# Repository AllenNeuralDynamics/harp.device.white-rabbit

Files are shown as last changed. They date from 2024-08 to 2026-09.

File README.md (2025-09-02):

An RP2040-based 16-output [Harp](https://github.com/harp-tech/protocol)-compliant Clock Synchronizer. 

This device can serve as a drop-in replacement for the [Harp-Tech Clock Synchronizer](https://github.com/harp-tech/device.clocksynchronizer) with added capabilities.

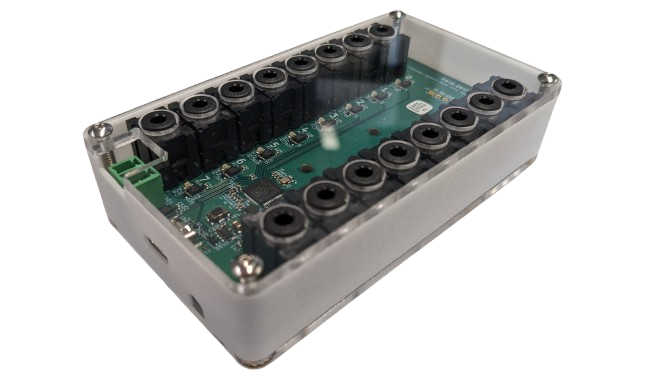
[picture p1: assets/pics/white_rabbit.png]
PCB


## Features
* 16 output channels for distributing clocks to other devices
* 1 input channel for receiving and synchronizing to another clock source
* 1 Additional Auxiliary Output, providing one of the following at a time:
  * PPS output
  * serial output of the time at user-specifiable baud-rate
* "Used channel detection." Device can identify which channels are in use.

## Ordering ➡ 💸
You can now order V1.0.0 from PCBWay:
* [white-rabbit board](https://www.pcbway.com/project/shareproject/W777629ASS64_W777629ASS46_white_rabbit_v1_0_0_gerbers_1c23dd35.html). Select **PCB + Assembly**

These printed circuit boards are made on-demand.

You will also need:
* [3D Printed Enclosure Walls and Laser Cut Lids](https://cad.onshape.com/documents/e58143a7c9dd2652647e9623/w/90e72faf89a0a2a445ca0911/e/b03806c0bc46a31dc8d5c2c5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)
  * right click the component to export each part.

## Auxiliary Output
This device features an auxiliary output that can either produce a *pulse-per-second* (PPS) or UART message at the start of the whole second.
This external signa enables Harp devices to additionally further synchronize with *non*-Harp devices.

### PPS Output
This device optionally outputs a 1[Hz] signal with a 50% duty cycle on the whole second.
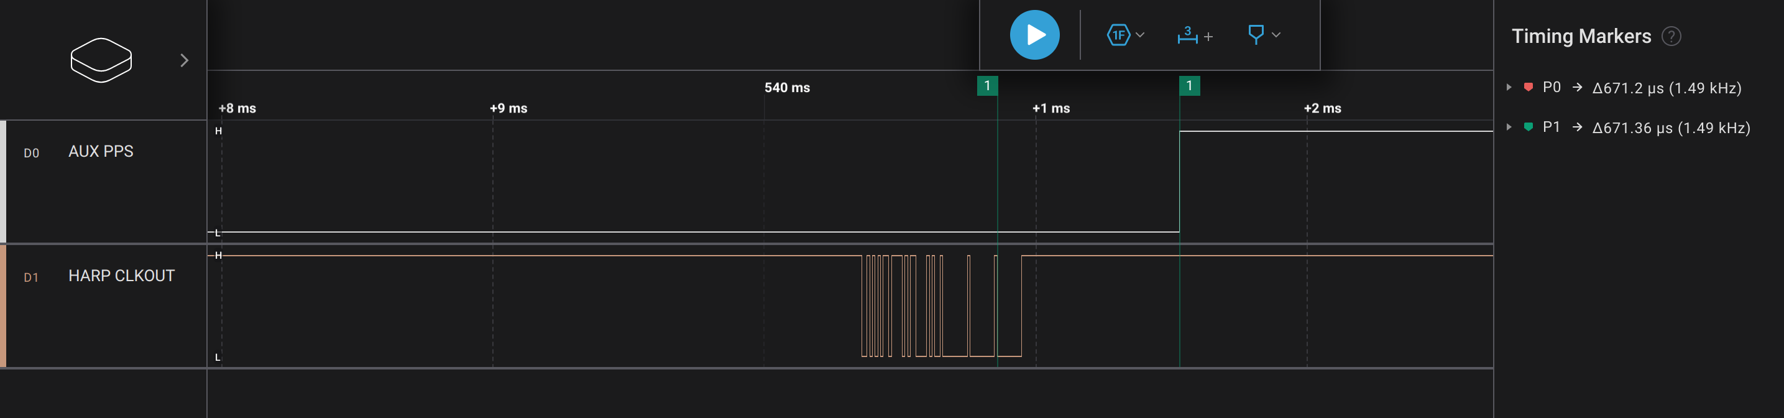
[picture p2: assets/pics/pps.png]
PPS

Error from the nominal Harp time is < 1[us].

This feature is available on the AUX Port (3-pin terminal block).

### AUX UART Output
This device optionally outputs a the current time in seconds at the start of the whole second.
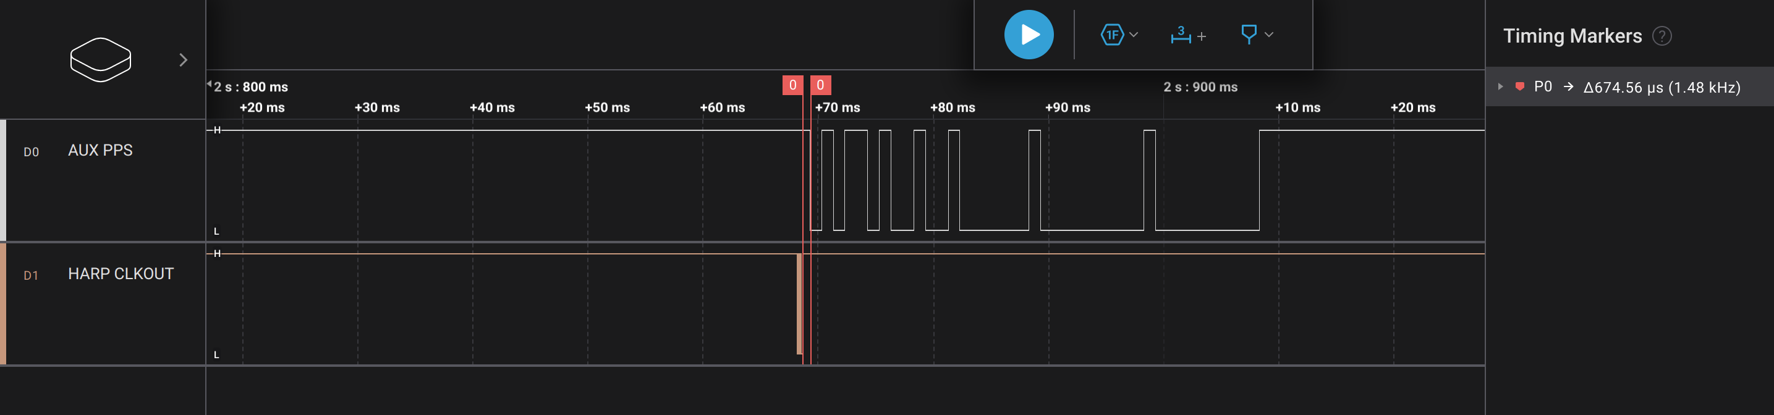
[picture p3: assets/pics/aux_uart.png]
AUX_UART

Error from the nominal Harp time is < 3[us].

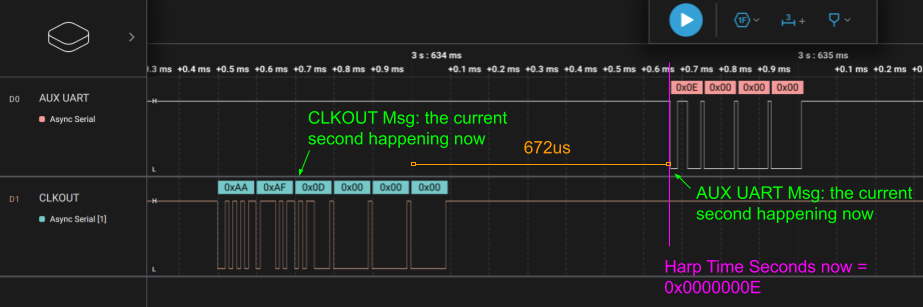
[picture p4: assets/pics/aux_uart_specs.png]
AUX_UART_ERROR


This feature is available on the AUX Port (3-pin terminal block), and the baud rate is configurable via Harp Protocol (U32 in Register 36).

## PCBA Enclosure
For the enclosure design, see the companion [OnShape project](https://cad.onshape.com/documents/e58143a7c9dd2652647e9623/w/90e72faf89a0a2a445ca0911/e/b03806c0bc46a31dc8d5c2c5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).

## Developer Notes
In the firmware's **CMakeLists.txt**, adding (or uncommenting) the debug message below:
````cmake
add_definitions(-DDEBUG)
````
will *override* the Auxiliary port behavior to use the auxiliary uart for `printf`-style debug messages.
`PPS` and `AUX UART` features will not be available in debug mode.

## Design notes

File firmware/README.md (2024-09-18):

## Setting up the Build Environment

### Install Submodules
This project uses the [Harp Core RP2040](https://github.com/AllenNeuralDynamics/harp.core.rp2040) library as a submodule.
Install it with:
````
git submodule update --init
````

### Install Pico SDK
This project uses the [Pico SDK](https://github.com/raspberrypi/pico-sdk/tree/master).
The SDK needs to be downloaded and installed to a known folder on your PC.
Note that the PICO SDK also contains submodules (including TinyUSB), so you must ensure that they are also fetched with:
````
git clone git@github.com:raspberrypi/pico-sdk.git
git submodule update --init --recursive
````

### Point to Pico SDK
Recommended, but optional: define the `PICO_SDK_PATH` environment variable to point to the location where the pico-sdk was downloaded. i.e:
````
PICO_SDK_PATH=/home/username/projects/pico-sdk
````
On Linux, it may be preferrable to put this in your `.bashrc` file.

## Compiling the Firmware

### Without an IDE
From this directory, create a directory called build, enter it, and invoke cmake with:
````
mkdir build
cd build
cmake ..
````
If you did not define the `PICO_SDK_PATH` as an environment variable, you must pass it in here like so:
````
mkdir build
cd build
cmake -DPICO_SDK_PATH=/path/to/pico-sdk ..
````
After this point, you can invoke the auto-generated Makefile with `make`

## Flashing the Firmware
Press-and-hold the Pico's BOOTSEL button and power it up (i.e: plug it into usb).
At this point you do one of the following:
* drag-and-drop the created **\*.uf2** file into the mass storage device that appears on your pc.
* flash with [picotool](https://github.com/raspberrypi/picotool)

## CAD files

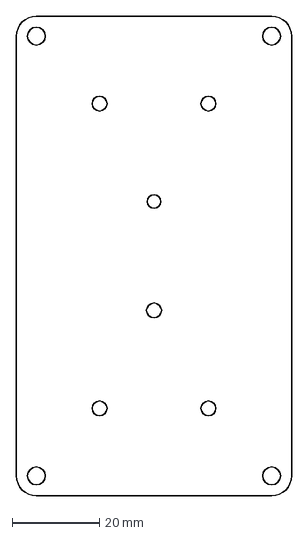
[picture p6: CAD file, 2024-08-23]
hardware/enclosure/exports/dxfs/offset/bottom_lid_offset.DXF
63.2 x 110.2 mm

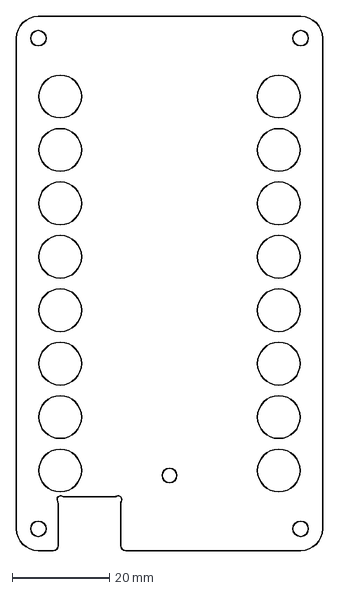
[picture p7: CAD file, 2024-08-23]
hardware/enclosure/exports/dxfs/original/top_lid.DXF
63.0 x 110.0 mm

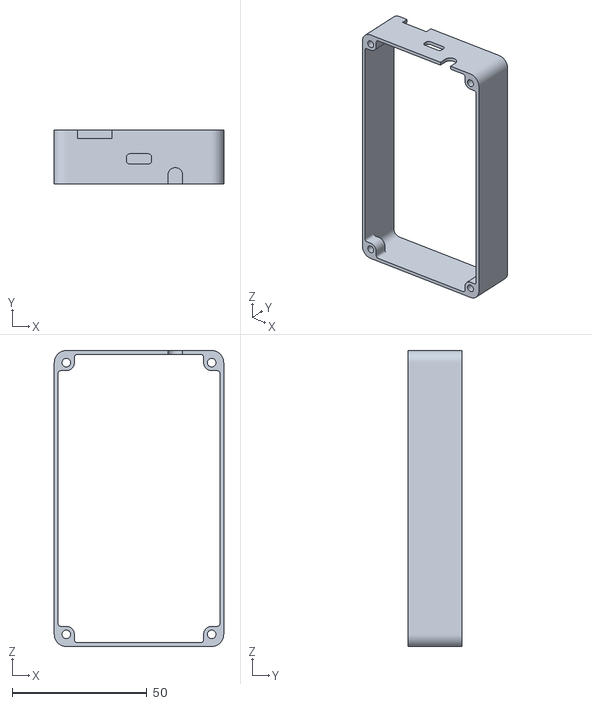
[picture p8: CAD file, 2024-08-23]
hardware/enclosure/exports/stls/case_walls.STL
63.0 x 19.9 x 110.0

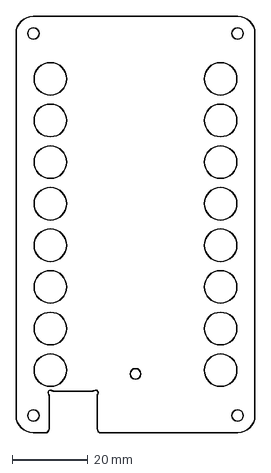
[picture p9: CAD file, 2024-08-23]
hardware/enclosure/exports/dxfs/offset/top_lid_offset.DXF
63.2 x 110.2 mm

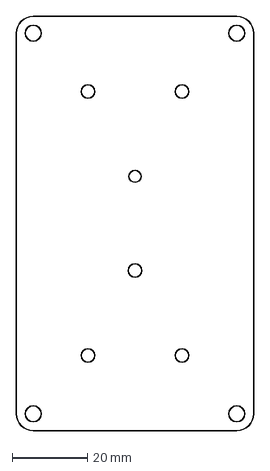
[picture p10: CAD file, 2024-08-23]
hardware/enclosure/exports/dxfs/original/bottom_lid.DXF
63.0 x 110.0 mm

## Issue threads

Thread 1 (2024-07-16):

Draft of register specification

bruno-f-cruz, 2024-07-16:
## Period generation of messages (Timer)
### Sends out periodic messages eg. 250hz (1 register for Event U32 counter, 1 Register for writing period/frequency)

e.g.:
```
 Timer:
    address: 33
    type: U32
    access: [Write, Event]
    description: Unitary counter that periodically produces a value at the frequency defined by register TimerFrequency.
  TimerFrequency:
    address: 34
    type: U8
    access: Write
    maskType: TimerRate
    description: Frequency at which the Timer will generate new values.
```

## IsConnected.
 U16 > each bit is a device/port connected(1) or not (0). Emit a message each time it changes.
eg.:
```
 DevicesConnected:
    address: 32
    type: U8
    access: Read
    maskType: ConnectedDevices
    description: Specifies which CLK_OUT ports have devices connected.
```

## Writable Seconds register
## Low 1kpbs / PPS

Poofjunior, 2024-07-17:
Ok, can I propose a few changes?

* 32: `connected_devices` instead of `DevicesConnected`
* 33: `heartbeat` instead of `Timer` (_[Heartbeat](https://en.wikipedia.org/wiki/Heartbeat_(computing)) has a standard meaning.)
* 34: `heartbeat_frequency_hz` instead of `TimerFrequency`
* 34: U16 instead of U8 and the value 0 - 1000 represents the actual publish rate instead of an enum of predefined values.

bruno-f-cruz, 2024-07-17:
I am fine with connected_devices as long as it is pascal casing :P

33 and 34 i really don't think we should call it heartbeat. For two reasons. 1) this register is not reporting the state of the device it is really just a "dumb" periodic event. 2) I think heartbeat is already co-opted by a recent proposal: https://github.com/harp-tech/protocol/pull/45

Poofjunior, 2024-07-17:
If not `heartbeat`, how about `counter` then?

Since these are scoped to Core and App registers, I'm totally ok with having overlapping names--especially since all core registers are [prefixed](https://harp-tech.org/protocol/Device.html#table---list-of-available-common-registers) with `R_`.

bruno-f-cruz, 2024-07-17:
Sure, the counter is ok. My only contention is whether to try to align interfaces across different devices if possible, as to only ask users to learn a single name, but if we want to go with something different i don't have a strong opinion. `Counter` sounds good.

Regarding the names, the decision is a bit more complicated. Since the bonsai/python interfaces are generated from the yml file, it is critical to have different names (otherwise users will have a really hard time knowing which one is which).

Poofjunior, 2024-07-17:
Ok, sounds good. `Counter` it is.

For the time when the message emits, is it critical that it falls on or near a particular whole number or multiple of a whole number?

bruno-f-cruz, 2024-07-17:
Nah do it whenever it crosses the expected time and the board is "available" to work. I would say that some deviation from the requested frequency is expected. At 250hz, 5% would be a good target?

Poofjunior, 2024-07-17:
Ok, coolies. Honestly, I expect it to be <1% deviation. Sending a USB transaction is the only "time-consuming" function device needs to execute. Nothing else blocks.

Poofjunior, 2024-07-18:
All right; here's what I've got so far:
````cpp
struct app_regs_t
{
    volatile uint16_t ConnectedDevices; // bitmask where each bit represents
                                         // whether a device is
                                         // connected (1) or disconnected (0)
                                         // to the corresponding clock output
                                         // channel.
    volatile uint32_t Counter;
    volatile uint16_t CounterFrequencyHz;
    volatile uint8_t AuxPortFn; // bit[0] = 1 --> slow uart
                                // bit[1] = 1 --> PPS
    // More app "registers" here.
};
````

We'll need to test these with Bonsai.

bruno-f-cruz, 2024-09-12:
I am closing this issue as we already have the spec

Closed 2024-09-12.

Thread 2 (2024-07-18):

Add Bonsai interface

bruno-f-cruz, 2024-07-18:
Follow the current spec:

https://github.com/AllenNeuralDynamics/harp.device.white-rabbit/blob/708e135fb53b5afd40ac85ea6d7713f9611dc87d/firmware/inc/white_rabbit_app.h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

bruno-f-cruz, 2024-08-01:
Closed by #3

Closed 2024-08-01.

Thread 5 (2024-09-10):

V1.0 TODOs

Poofjunior, 2024-09-10:
- [x] Check that heartbeat timestamps agree on a White Rabbit and a device synchronized to it.
- [x] Check that AUX PPS signal rising edge emits 672 microseconds after the start of the last byte of the last emitted CKLOUT message.
- [x] Check that AUX UART message first falling edge emits 672 microseconds after the start of the last byte of the last emitted CLKOUT message.
- [x] Check that time encoded by UART is the second that just elapsed.
- [x] Hardware/FW Versions available in Harp Protocol

Poofjunior, 2024-09-11:
For the last point:
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

Closed 2024-09-12.

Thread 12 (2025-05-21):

`ClockConfiguration` register is not set correctly

bruno-f-cruz, 2025-05-21:
Querying the register returns:

```
               None  ClockRepeater  ClockGenerator  RepeaterCapability  GeneratorCapability  ClockUnlock  ClockLock MessageType
Time                                                                                                                  
3.601605e+06  False          False           False               False                False        False      False        READ
```

Some of these are expected to be high for a clock generator:
https://harp-tech.org/protocol/Device.html#r_clock_config-u8--synchronization-clock-configuration

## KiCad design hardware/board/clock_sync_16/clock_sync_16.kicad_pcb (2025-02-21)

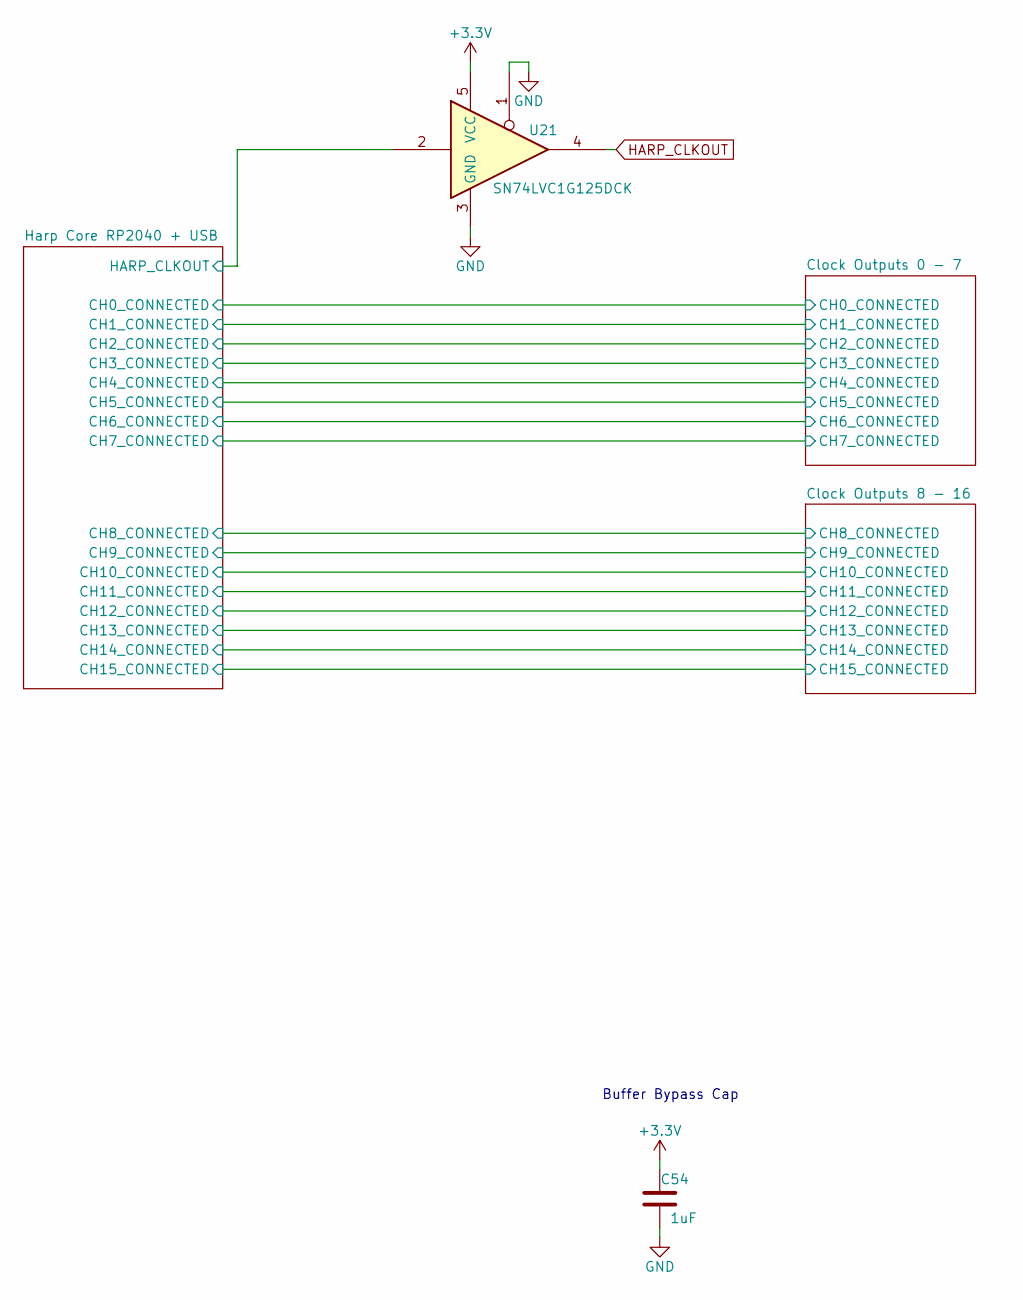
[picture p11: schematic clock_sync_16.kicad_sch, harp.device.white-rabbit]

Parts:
C54: 1uF; C_0402_1005Metric; Rated Voltage 35V
U21: SN74LVC1G125DCK; Texas_R-PDSO-G5_DCK-5

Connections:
+3.3V: C54.1, U21.5 (VCC); also elsewhere on the board
/Harp Core RP2040 + USB/HARP_CLKOUT: U21.2; also elsewhere on the board
GND: C54.2, U21.1, U21.3 (GND); also elsewhere on the board
HARP_CLKOUT: U21.4; also elsewhere on the board

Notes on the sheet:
Buffer Bypass Cap

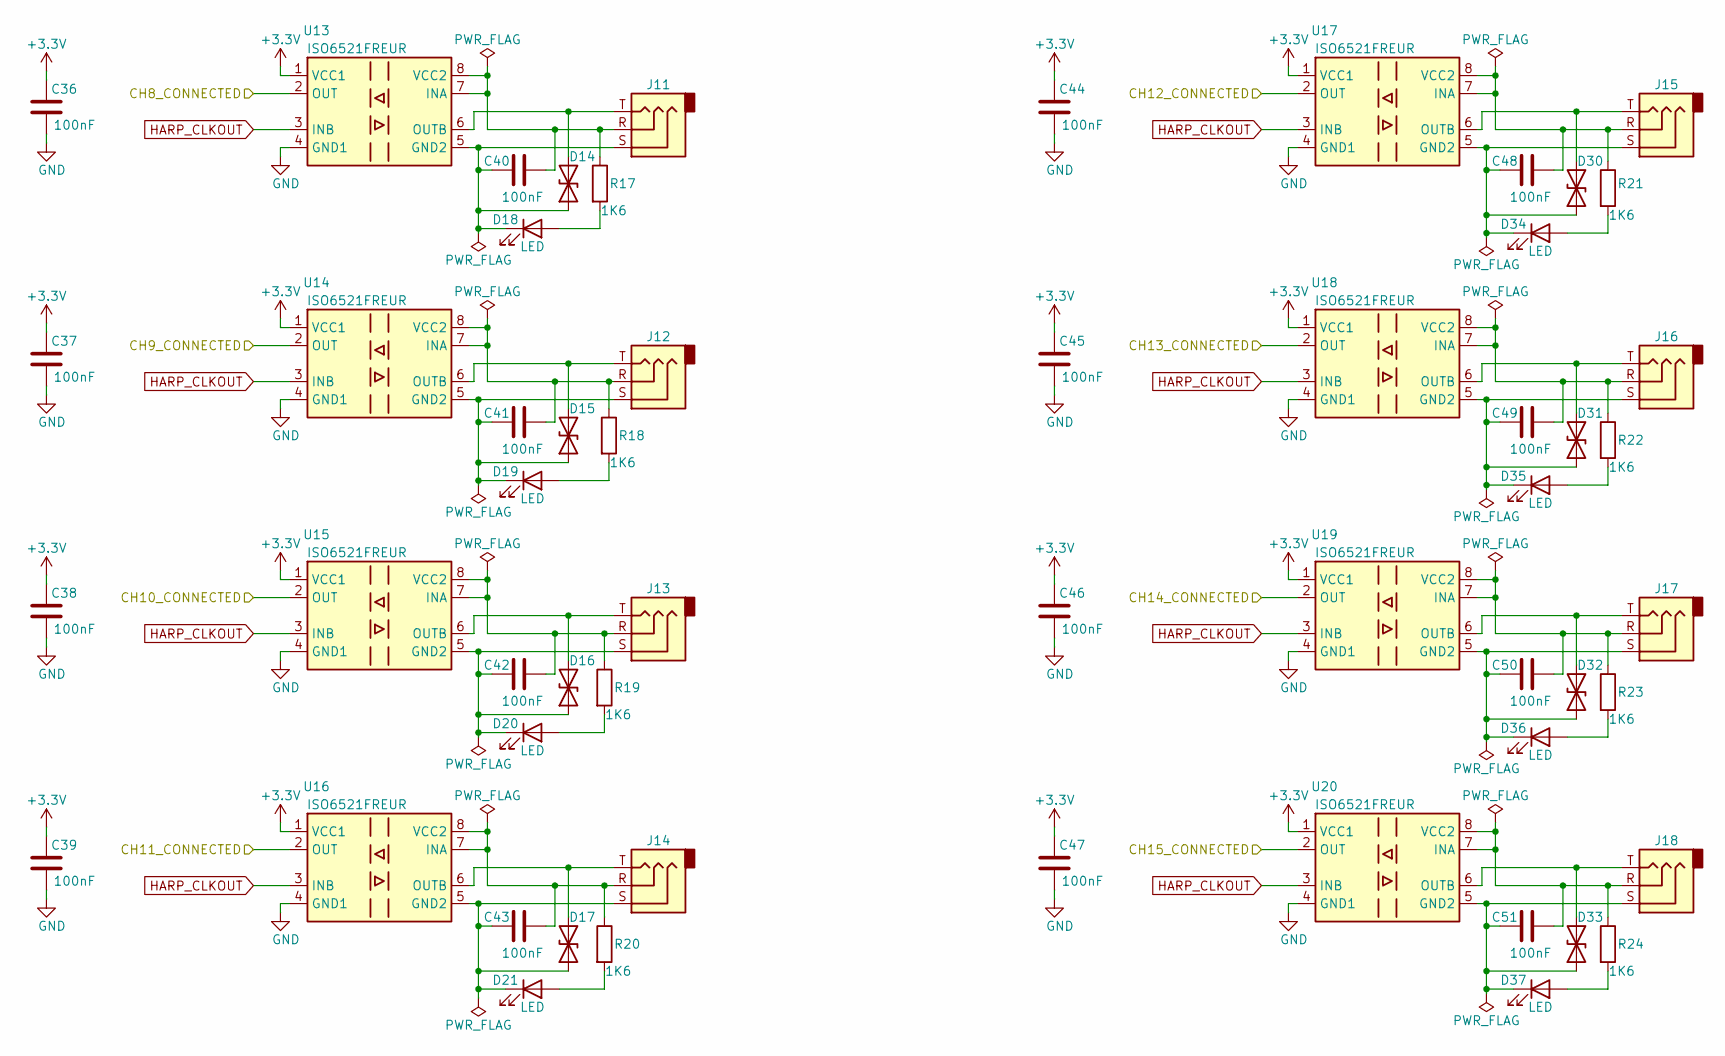
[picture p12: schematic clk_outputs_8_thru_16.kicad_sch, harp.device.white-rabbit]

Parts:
C36, C37, C38, C39, C40, C41, C42, C43, C44, C45, C46, C47, C48, C49, C50, C51: 100nF; C_0402_1005Metric; Rated Voltage 16V; Tolerance 10%
D14, D15, D16, D17, D30, D31, D32, D33: D_TVS; D_0402_1005Metric
D18, D19, D20, D21, D34, D35, D36, D37: LED; LED_0603_1608Metric_Pad1.05x0.95mm_HandSolder
J11, J12, J13, J14, J15, J16, J17, J18: AudioJack3; Jack_3.5mm_Kycon_STX-3680-5NB_Vertical
R17, R18, R19, R20, R21, R22, R23, R24: 1K6; R_0402_1005Metric
U13, U14, U15, U16, U17, U18, U19, U20: ISO6521FREUR; DFN-8_3x2mm_P0.5mm

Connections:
+3.3V: C36.2, C37.2, C38.2, C39.2, C44.2, C45.2, C46.2, C47.2, U13.1 (VCC1), U14.1 (VCC1), U15.1 (VCC1), U16.1 (VCC1), U17.1 (VCC1), U18.1 (VCC1), U19.1 (VCC1), U20.1 (VCC1); also elsewhere on the board
/Clock Outputs 8 - 16/CH8_CONNECTED: U13.2 (OUT); also elsewhere on the board
/Clock Outputs 8 - 16/CH9_CONNECTED: U14.2 (OUT); also elsewhere on the board
/Clock Outputs 8 - 16/CH10_CONNECTED: U15.2 (OUT); also elsewhere on the board
/Clock Outputs 8 - 16/CH11_CONNECTED: U16.2 (OUT); also elsewhere on the board
/Clock Outputs 8 - 16/CH12_CONNECTED: U17.2 (OUT); also elsewhere on the board
/Clock Outputs 8 - 16/CH13_CONNECTED: U18.2 (OUT); also elsewhere on the board
/Clock Outputs 8 - 16/CH14_CONNECTED: U19.2 (OUT); also elsewhere on the board
/Clock Outputs 8 - 16/CH15_CONNECTED: U20.2 (OUT); also elsewhere on the board
GND: C36.1, C37.1, C38.1, C39.1, C44.1, C45.1, C46.1, C47.1, U13.4 (GND1), U14.4 (GND1), U15.4 (GND1), U16.4 (GND1), U17.4 (GND1), U18.4 (GND1), U19.4 (GND1), U20.4 (GND1); also elsewhere on the board
HARP_CLKOUT: U13.3 (INB), U14.3 (INB), U15.3 (INB), U16.3 (INB), U17.3 (INB), U18.3 (INB), U19.3 (INB), U20.3 (INB); also elsewhere on the board
unnamed: C40.2, D14.1 (A1), D18.1 (K), J11.S, U13.5 (GND2)
unnamed: D14.2 (A2), J11.T, U13.6 (OUTB)
unnamed: C41.2, D15.1 (A1), D19.1 (K), J12.S, U14.5 (GND2)
unnamed: D15.2 (A2), J12.T, U14.6 (OUTB)
unnamed: C42.2, D16.1 (A1), D20.1 (K), J13.S, U15.5 (GND2)
unnamed: D16.2 (A2), J13.T, U15.6 (OUTB)
unnamed: C43.2, D17.1 (A1), D21.1 (K), J14.S, U16.5 (GND2)
unnamed: D17.2 (A2), J14.T, U16.6 (OUTB)
unnamed: D18.2 (A), R17.2
unnamed: D19.2 (A), R18.2
unnamed: D20.2 (A), R19.2
unnamed: D21.2 (A), R20.2
unnamed: C48.2, D30.1 (A1), D34.1 (K), J15.S, U17.5 (GND2)
unnamed: D30.2 (A2), J15.T, U17.6 (OUTB)
unnamed: C49.2, D31.1 (A1), D35.1 (K), J16.S, U18.5 (GND2)
unnamed: D31.2 (A2), J16.T, U18.6 (OUTB)
unnamed: C50.2, D32.1 (A1), D36.1 (K), J17.S, U19.5 (GND2)
unnamed: D32.2 (A2), J17.T, U19.6 (OUTB)
unnamed: C51.2, D33.1 (A1), D37.1 (K), J18.S, U20.5 (GND2)
unnamed: D33.2 (A2), J18.T, U20.6 (OUTB)
unnamed: D34.2 (A), R21.2
unnamed: D35.2 (A), R22.2
unnamed: D36.2 (A), R23.2
unnamed: D37.2 (A), R24.2
unnamed: C40.1, J11.R, R17.1, U13.7 (INA), U13.8 (VCC2)
unnamed: C41.1, J12.R, R18.1, U14.7 (INA), U14.8 (VCC2)
unnamed: C42.1, J13.R, R19.1, U15.7 (INA), U15.8 (VCC2)
unnamed: C43.1, J14.R, R20.1, U16.7 (INA), U16.8 (VCC2)
unnamed: C48.1, J15.R, R21.1, U17.7 (INA), U17.8 (VCC2)
unnamed: C49.1, J16.R, R22.1, U18.7 (INA), U18.8 (VCC2)
unnamed: C50.1, J17.R, R23.1, U19.7 (INA), U19.8 (VCC2)
unnamed: C51.1, J18.R, R24.1, U20.7 (INA), U20.8 (VCC2)

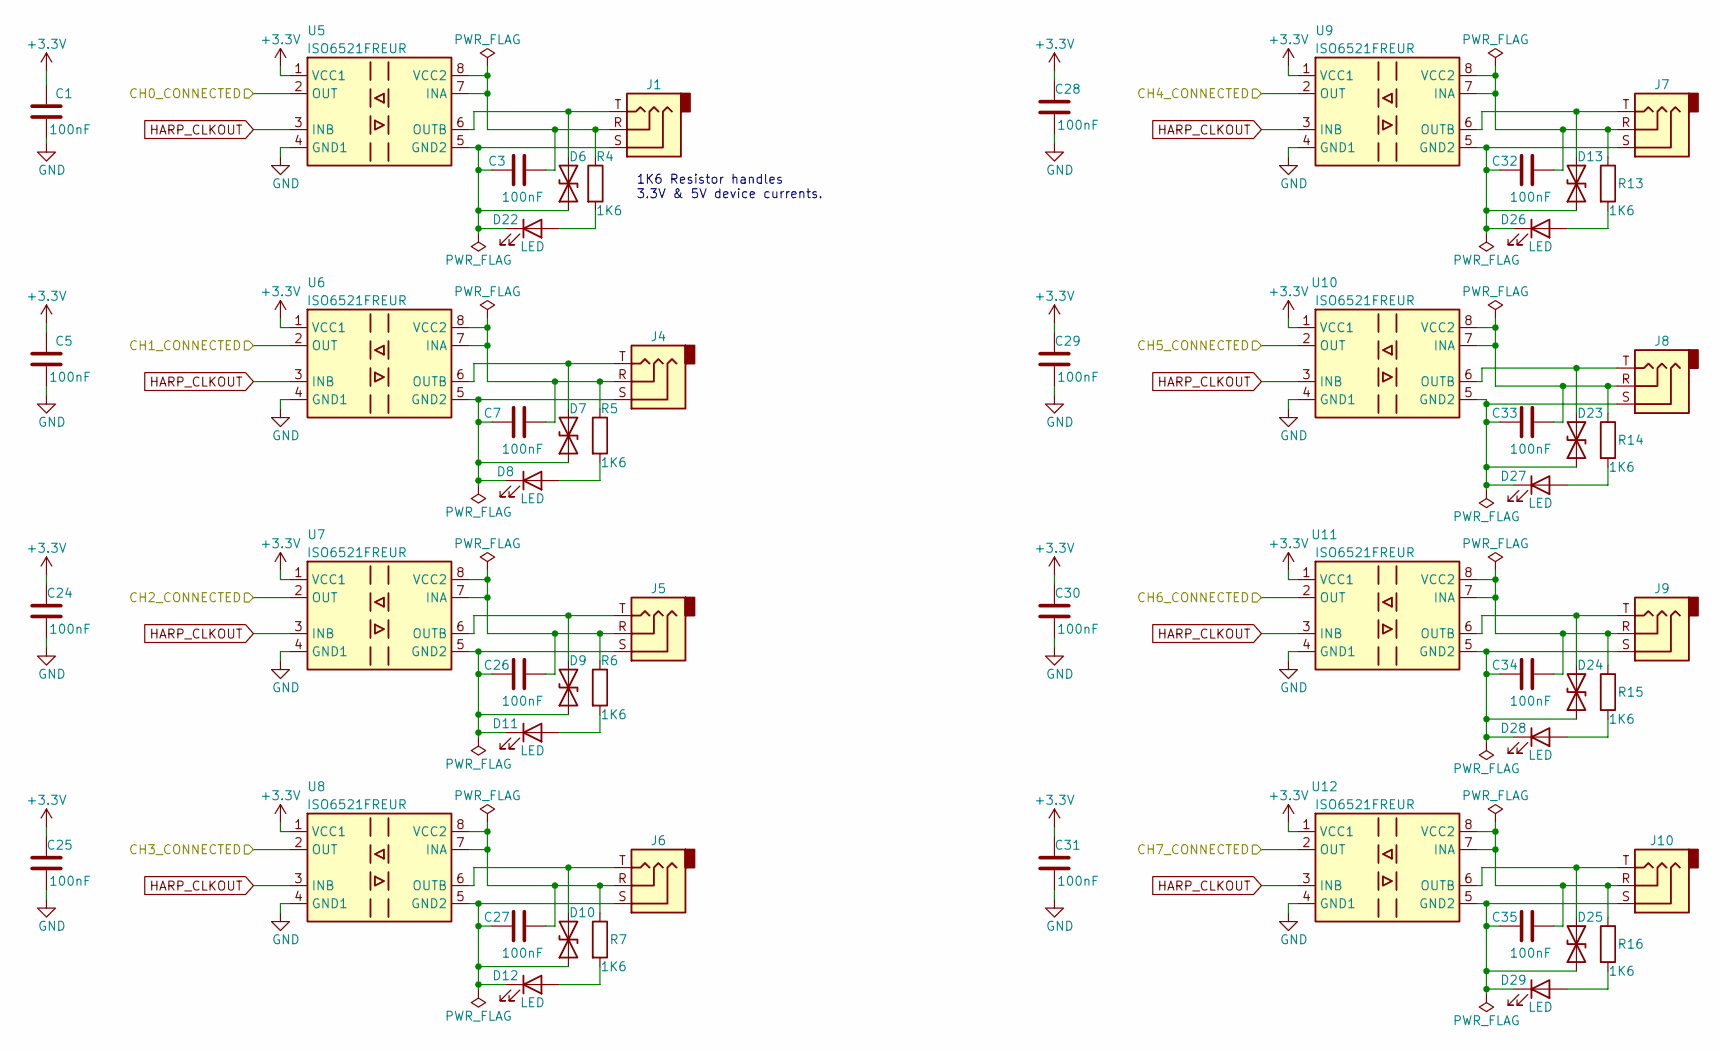
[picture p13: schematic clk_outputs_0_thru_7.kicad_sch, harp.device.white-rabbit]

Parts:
C1, C3, C5, C7, C24, C25, C26, C27, C28, C29, C30, C31, C32, C33, C34, C35: 100nF; C_0402_1005Metric; Rated Voltage 16V; Tolerance 10%
D6, D7, D9, D10, D13, D23, D24, D25: D_TVS; D_0402_1005Metric
D8, D11, D12, D22, D26, D27, D28, D29: LED; LED_0603_1608Metric_Pad1.05x0.95mm_HandSolder
J1, J4, J5, J6, J7, J8, J9, J10: AudioJack3; Jack_3.5mm_Kycon_STX-3680-5NB_Vertical
R4, R5, R6, R7, R13, R14, R15, R16: 1K6; R_0402_1005Metric
U5, U6, U7, U8, U9, U10, U11, U12: ISO6521FREUR; DFN-8_3x2mm_P0.5mm

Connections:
+3.3V: C1.2, C5.2, C24.2, C25.2, C28.2, C29.2, C30.2, C31.2, U5.1 (VCC1), U6.1 (VCC1), U7.1 (VCC1), U8.1 (VCC1), U9.1 (VCC1), U10.1 (VCC1), U11.1 (VCC1), U12.1 (VCC1); also elsewhere on the board
/Clock Outputs 0 - 7/CH0_CONNECTED: U5.2 (OUT); also elsewhere on the board
/Clock Outputs 0 - 7/CH1_CONNECTED: U6.2 (OUT); also elsewhere on the board
/Clock Outputs 0 - 7/CH2_CONNECTED: U7.2 (OUT); also elsewhere on the board
/Clock Outputs 0 - 7/CH3_CONNECTED: U8.2 (OUT); also elsewhere on the board
/Clock Outputs 0 - 7/CH4_CONNECTED: U9.2 (OUT); also elsewhere on the board
/Clock Outputs 0 - 7/CH5_CONNECTED: U10.2 (OUT); also elsewhere on the board
/Clock Outputs 0 - 7/CH6_CONNECTED: U11.2 (OUT); also elsewhere on the board
/Clock Outputs 0 - 7/CH7_CONNECTED: U12.2 (OUT); also elsewhere on the board
GND: C1.1, C5.1, C24.1, C25.1, C28.1, C29.1, C30.1, C31.1, U5.4 (GND1), U6.4 (GND1), U7.4 (GND1), U8.4 (GND1), U9.4 (GND1), U10.4 (GND1), U11.4 (GND1), U12.4 (GND1); also elsewhere on the board
HARP_CLKOUT: U5.3 (INB), U6.3 (INB), U7.3 (INB), U8.3 (INB), U9.3 (INB), U10.3 (INB), U11.3 (INB), U12.3 (INB); also elsewhere on the board
unnamed: D6.2 (A2), J1.T, U5.6 (OUTB)
unnamed: C7.2, D7.1 (A1), D8.1 (K), J4.S, U6.5 (GND2)
unnamed: D7.2 (A2), J4.T, U6.6 (OUTB)
unnamed: D8.2 (A), R5.2
unnamed: D9.2 (A2), J5.T, U7.6 (OUTB)
unnamed: C27.2, D10.1 (A1), D12.1 (K), J6.S, U8.5 (GND2)
unnamed: D10.2 (A2), J6.T, U8.6 (OUTB)
unnamed: D11.2 (A), R6.2
unnamed: C26.2, D9.1 (A1), D11.1 (K), J5.S, U7.5 (GND2)
unnamed: D12.2 (A), R7.2
unnamed: C32.2, D13.1 (A1), D26.1 (K), J7.S, U9.5 (GND2)
unnamed: D13.2 (A2), J7.T, U9.6 (OUTB)
unnamed: D22.2 (A), R4.2
unnamed: C3.2, D6.1 (A1), D22.1 (K), J1.S, U5.5 (GND2)
unnamed: C33.2, D23.1 (A1), D27.1 (K), J8.S, U10.5 (GND2)
unnamed: D23.2 (A2), J8.T, U10.6 (OUTB)
unnamed: C34.2, D24.1 (A1), D28.1 (K), J9.S, U11.5 (GND2)
unnamed: D24.2 (A2), J9.T, U11.6 (OUTB)
unnamed: C35.2, D25.1 (A1), D29.1 (K), J10.S, U12.5 (GND2)
unnamed: D25.2 (A2), J10.T, U12.6 (OUTB)
unnamed: D26.2 (A), R13.2
unnamed: D27.2 (A), R14.2
unnamed: D28.2 (A), R15.2
unnamed: D29.2 (A), R16.2
unnamed: C3.1, J1.R, R4.1, U5.7 (INA), U5.8 (VCC2)
unnamed: C7.1, J4.R, R5.1, U6.7 (INA), U6.8 (VCC2)
unnamed: C26.1, J5.R, R6.1, U7.7 (INA), U7.8 (VCC2)
unnamed: C27.1, J6.R, R7.1, U8.7 (INA), U8.8 (VCC2)
unnamed: C32.1, J7.R, R13.1, U9.7 (INA), U9.8 (VCC2)
unnamed: C33.1, J8.R, R14.1, U10.7 (INA), U10.8 (VCC2)
unnamed: C34.1, J9.R, R15.1, U11.7 (INA), U11.8 (VCC2)
unnamed: C35.1, J10.R, R16.1, U12.7 (INA), U12.8 (VCC2)

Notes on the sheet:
1K6 Resistor handles 3.3V & 5V device currents.

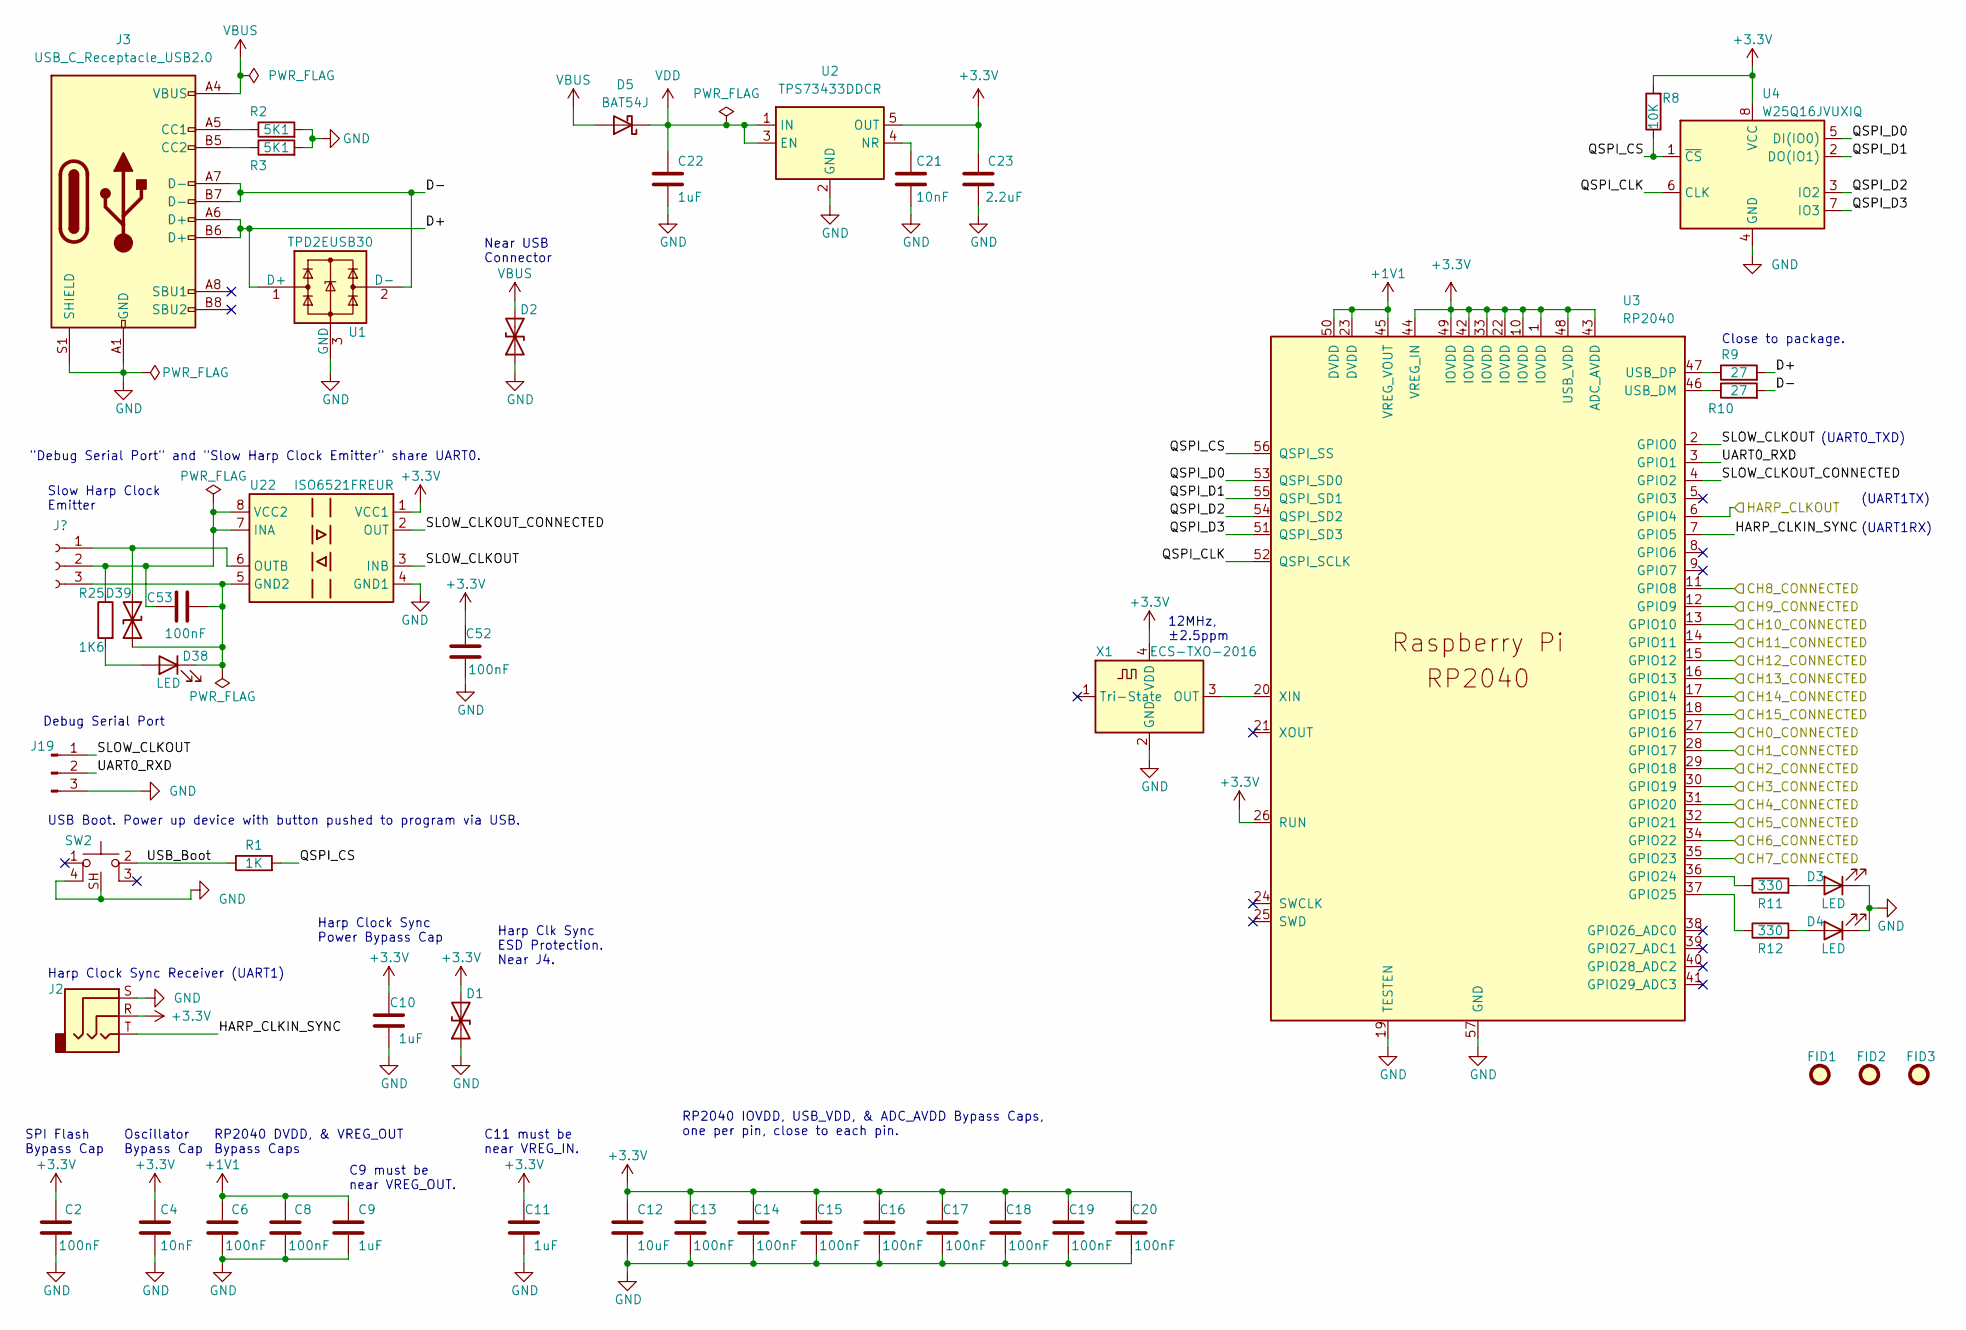
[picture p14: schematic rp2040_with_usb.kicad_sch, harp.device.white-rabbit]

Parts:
C2, C6, C8, C13, C14, C15, C16, C17, C18, C19, C20, C52, C53: 100nF; C_0402_1005Metric; Rated Voltage 16V; Tolerance 10%
C4, C21: 10nF; C_0402_1005Metric; Rated Voltage 25V; Tolerance 2%
C9, C10, C11, C22: 1uF; C_0402_1005Metric; Rated Voltage 35V
C12: 10uF; C_0805_2012Metric; Rated Voltage 25V
C23: 2.2uF; C_0402_1005Metric; Rated Voltage 10V
D1, D2, D39: D_TVS; D_0402_1005Metric
D3, D4, D38: LED; LED_0603_1608Metric_Pad1.05x0.95mm_HandSolder
D5: BAT54J; D_SOD-323F
FID1, FID2, FID3: Fiducial; Fiducial_0.5mm_Mask1mm
J1: Conn_01x03_Female; PhoenixContact_MCV_1,5_3-G-3.5_1x03_P3.50mm_Vertical
J2: AudioJack3; Jack_3.5mm_CUI_SJ-3524-SMT_Horizontal
J3: USB_C_Receptacle_USB2.0; USB_C_Receptacle_JAE_DX07S016JA1R1500
J19: Conn_01x03_Male; PinHeader_1x03_P2.54mm_Vertical
R1: 1K; R_0402_1005Metric; Tolerance 1%
R2, R3: 5K1; R_0402_1005Metric; Tolerance 1%
R8: 10K; R_0402_1005Metric; Tolerance 1%
R9, R10: 27; R_0402_1005Metric; Tolerance 1%
R11, R12: 330; R_0402_1005Metric; Tolerance 0.1%
R25: 1K6; R_0402_1005Metric
SW2: SW_Push_1P1T-SH_NO_Vertical_Wuerth_WS-TASV
U1: TPD2EUSB30; Texas_DRT-3
U2: TPS73433DDCR; SOT-23-5
U3: RP2040; RP2040-QFN-56
U4: W25Q16JVUXIQ; Winbond-8USON-2x3mm
U22: ISO6521FREUR; DFN-8_3x2mm_P0.5mm
X1: ECS-TXO-2016; Crystal_SMD_2016-4Pin_2.0x1.6mm; Tolerance ±2.5ppm

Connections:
+1V1: C6.2, C8.2, C9.1, U3.23 (DVDD), U3.45 (VREG_VOUT), U3.50 (DVDD)
+3.3V: C2.2, C4.1, C10.1, C11.1, C12.1, C13.2, C14.2, C15.2, C16.2, C17.2, C18.2, C19.2, C20.2, C23.2, C52.2, D1.2 (A2), J2.R, R8.2, U2.5 (OUT), U3.1 (IOVDD), U3.10 (IOVDD), U3.22 (IOVDD), U3.26 (RUN), U3.33 (IOVDD), U3.42 (IOVDD), U3.43 (ADC_AVDD), U3.44 (VREG_IN), U3.48 (USB_VDD), U3.49 (IOVDD), U4.8 (VCC), U22.1 (VCC1), X1.4 (VDD); also elsewhere on the board
/Clock Outputs 0 - 7/CH0_CONNECTED: U3.27 (GPIO16); also elsewhere on the board
/Clock Outputs 0 - 7/CH1_CONNECTED: U3.28 (GPIO17); also elsewhere on the board
/Clock Outputs 0 - 7/CH2_CONNECTED: U3.29 (GPIO18); also elsewhere on the board
/Clock Outputs 0 - 7/CH3_CONNECTED: U3.30 (GPIO19); also elsewhere on the board
/Clock Outputs 0 - 7/CH4_CONNECTED: U3.31 (GPIO20); also elsewhere on the board
/Clock Outputs 0 - 7/CH5_CONNECTED: U3.32 (GPIO21); also elsewhere on the board
/Clock Outputs 0 - 7/CH6_CONNECTED: U3.34 (GPIO22); also elsewhere on the board
/Clock Outputs 0 - 7/CH7_CONNECTED: U3.35 (GPIO23); also elsewhere on the board
/Clock Outputs 8 - 16/CH8_CONNECTED: U3.11 (GPIO8); also elsewhere on the board
/Clock Outputs 8 - 16/CH9_CONNECTED: U3.12 (GPIO9); also elsewhere on the board
/Clock Outputs 8 - 16/CH10_CONNECTED: U3.13 (GPIO10); also elsewhere on the board
/Clock Outputs 8 - 16/CH11_CONNECTED: U3.14 (GPIO11); also elsewhere on the board
/Clock Outputs 8 - 16/CH12_CONNECTED: U3.15 (GPIO12); also elsewhere on the board
/Clock Outputs 8 - 16/CH13_CONNECTED: U3.16 (GPIO13); also elsewhere on the board
/Clock Outputs 8 - 16/CH14_CONNECTED: U3.17 (GPIO14); also elsewhere on the board
/Clock Outputs 8 - 16/CH15_CONNECTED: U3.18 (GPIO15); also elsewhere on the board
/Harp Core RP2040 + USB/D+: J3.A6 (D+), J3.B6 (D+), R9.2, U1.1 (D+)
/Harp Core RP2040 + USB/D-: J3.A7 (D-), J3.B7 (D-), R10.2, U1.2 (D-)
/Harp Core RP2040 + USB/HARP_CLKIN_SYNC: J2.T, U3.7 (GPIO5)
/Harp Core RP2040 + USB/HARP_CLKOUT: U3.6 (GPIO4); also elsewhere on the board
/Harp Core RP2040 + USB/QSPI_CLK: U3.52 (QSPI_SCLK), U4.6 (CLK)
/Harp Core RP2040 + USB/QSPI_CS: R1.2, R8.1, U3.56 (QSPI_SS), U4.1 (~CS)
/Harp Core RP2040 + USB/QSPI_D0: U3.53 (QSPI_SD0), U4.5 (DI(IO0))
/Harp Core RP2040 + USB/QSPI_D1: U3.55 (QSPI_SD1), U4.2 (DO(IO1))
/Harp Core RP2040 + USB/QSPI_D2: U3.54 (QSPI_SD2), U4.3 (IO2)
/Harp Core RP2040 + USB/QSPI_D3: U3.51 (QSPI_SD3), U4.7 (IO3)
/Harp Core RP2040 + USB/SLOW_CLKOUT: J19.1, U3.2 (GPIO0), U22.3 (INB)
/Harp Core RP2040 + USB/SLOW_CLKOUT_CONNECTED: U3.4 (GPIO2), U22.2 (OUT)
/Harp Core RP2040 + USB/UART0_RXD: J19.2, U3.3 (GPIO1)
/Harp Core RP2040 + USB/USB_Boot: R1.1, SW2.2
GND: C2.1, C4.2, C6.1, C8.1, C9.2, C10.2, C11.2, C12.2, C13.1, C14.1, C15.1, C16.1, C17.1, C18.1, C19.1, C20.1, C21.2, C22.2, C23.1, C52.1, D1.1 (A1), D2.1 (A1), D3.1 (K), D4.1 (K), J2.S, J3.A1 (GND), J3.A12 (GND), J3.B1 (GND), J3.B12 (GND), J3.S1 (SHIELD), J19.3, R2.2, R3.2, SW2.4, SW2.SH, U1.3 (GND), U2.2 (GND), U3.19 (TESTEN), U3.57 (GND), U4.4 (GND), U22.4 (GND1), X1.2 (GND); also elsewhere on the board
unnamed: D3.2 (A), R11.2
unnamed: D4.2 (A), R12.2
unnamed: D38.2 (A), R25.2
unnamed: J3.A5 (CC1), R2.1
unnamed: J3.B5 (CC2), R3.1
unnamed: C21.1, U2.4 (NR)
unnamed: R11.1, U3.36 (GPIO24)
unnamed: R12.1, U3.37 (GPIO25)
unnamed: R10.1, U3.46 (USB_DM)
unnamed: R9.1, U3.47 (USB_DP)
unnamed: U3.20 (XIN), X1.3 (OUT)
VBUS: D2.2 (A2), D5.2 (A), J3.A4 (VBUS), J3.A9 (VBUS), J3.B4 (VBUS), J3.B9 (VBUS)
VDD: C22.1, D5.1 (K), U2.1 (IN), U2.3 (EN)

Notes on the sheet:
C11 must be near VREG_IN.
"Debug Serial Port" and "Slow Harp Clock Emitter" share UART0.
C9 must be near VREG_OUT.
SPI Flash Bypass Cap
Close to package.
Harp Clock Sync Power Bypass Cap
Harp Clock Sync Receiver (UART1)
Oscillator Bypass Cap
RP2040 DVDD, & VREG_OUT Bypass Caps
Debug Serial Port
USB Boot. Power up device with button pushed to program via USB.
(UART0_TXD)
(UART1TX) (UART1RX)
RP2040 IOVDD, USB_VDD, & ADC_AVDD Bypass Caps, one per pin, close to each pin.
Near USB Connector
Slow Harp Clock Emitter
12MHz, ±2.5ppm
Harp Clk Sync ESD Protection. Near J4.

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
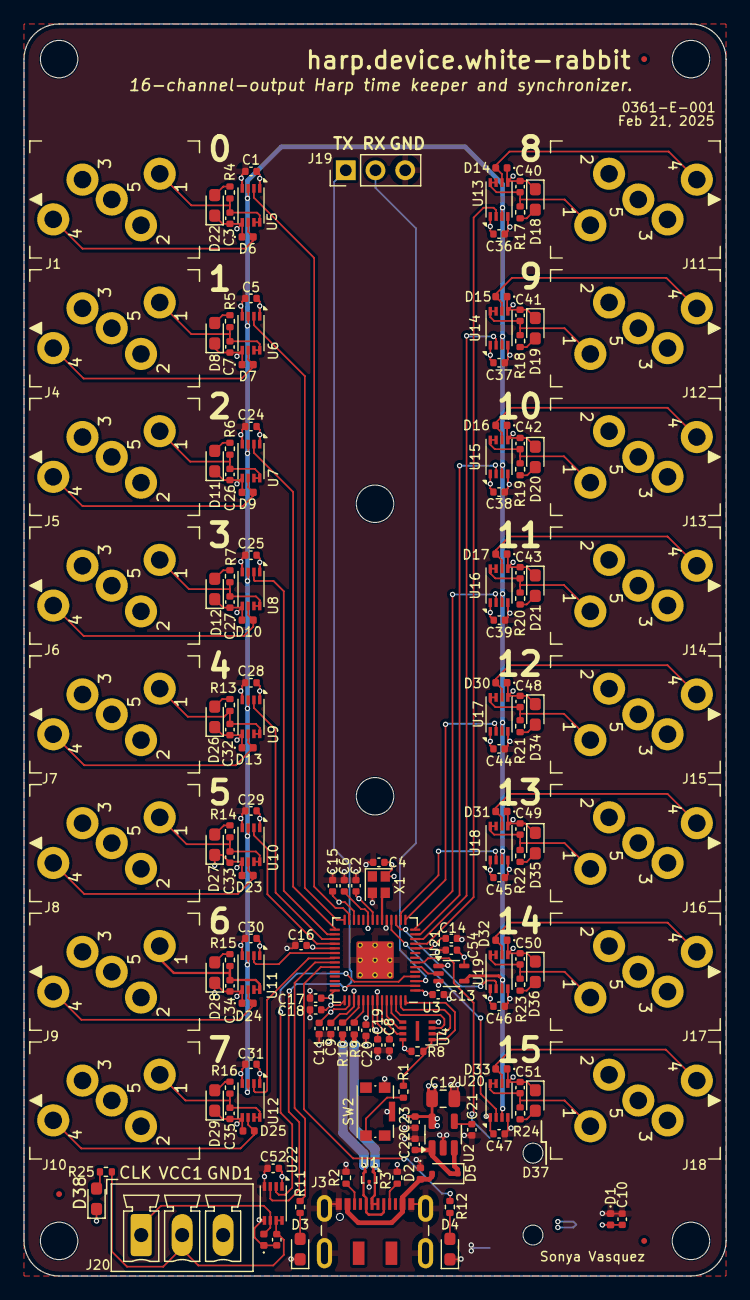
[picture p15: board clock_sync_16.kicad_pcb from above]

Board: 4 copper layers, 60.0 x 107.0 mm, 165 parts (1 on the bottom side), 114 nets.

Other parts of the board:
J20: Conn_01x03_Female; PhoenixContact_MCV_1,5_3-G-3.5_1x03_P3.50mm_Vertical

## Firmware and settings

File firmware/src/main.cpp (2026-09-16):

#include "config.h"
#include "core_registers.h"
#include "harp_core.h"
#include "harp_c_app.h"
#include "harp_synchronizer.h"
#include "reg_types.h"
#include "pico/unique_id.h"
#include "uart_nonblocking.h"
#include "white_rabbit_app.h"
#include <cstring>

const uint8_t interface_hash[20] = INTERFACE_HASH;

void set_harp_core_led(bool led_state)
{gpio_put(HARP_CORE_LED_PIN, led_state);}

bool get_harp_core_led_state()
{ return gpio_get(HARP_CORE_LED_PIN);}

// Core0 main.
int main()
{
#if defined(DEBUG)
#warning "Auxilary Port functionality will be overwritten to dispatch UART DEBUG msgs at 921600bps."
    stdio_uart_init_full(AUX_SYNC_UART, 921600, AUX_PIN, -1); // TX only.
    printf("Hello, from an RP2040!\r\n");
#endif
    // Setup OP_LED
    gpio_init(HARP_CORE_LED_PIN);
    gpio_set_dir(HARP_CORE_LED_PIN, GPIO_OUT);
    gpio_put(HARP_CORE_LED_PIN, 0);
    // Init Synchronizer. Do this first since the WhiteRabbit app will attempt
    // to initialize the same hardware (HARP_UART) and skip if already
    // initialized.
    HarpSynchronizer& sync = HarpSynchronizer::init(HARP_UART, HARP_CLKIN_PIN);
    // Create Harp App.
    HarpCApp& app = HarpCApp::init(HARP_DEVICE_ID, FW_VERSION, HW_VERSION,
                                   "White Rabbit",
                                   (uint8_t*)GIT_HASH, interface_hash,
                                   app_reg_specs, APP_REG_COUNT,
                                   update_app_state, reset_app);
    app.set_op_led_fns(set_harp_core_led, get_harp_core_led_state);
    app.set_is_clock_generator(true);

    app.set_synchronizer(&sync);
    // TODO: try waiting until synchronized.
    // If we enable debug msgs, we cannot use the slow output.
    reset_app();
    while(true)
        app.run();
}

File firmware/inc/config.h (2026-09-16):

#ifndef CONFIG_H
#define CONFIG_H
#include <cstdint>
#include "core_registers.h" // for semver_t

inline constexpr semver_t HW_VERSION = {1, 0, 0};
inline constexpr semver_t FW_VERSION = {0, 2, 0};

inline constexpr uint32_t HARP_CORE_LED_PIN = 25;

inline constexpr size_t HARP_DEVICE_ID = 1404;

#define HARP_UART (uart1)
// Baud rate and offset defined as constants in the core.
// https://harp-tech.org/protocol/SynchronizationClock.html
#define HARP_CLKOUT_PIN (4)
#define HARP_CLKIN_PIN (5)
#define HARP_SYNC_START_OFFSET_US (-1172) // Offset from spec to account for
                                          // transmission time.
                                          // Spec is: next whole second occurs
                                          // 672 us after the start of the last
                                          // byte. We offset another 500us
                                          // (5[bytes]*100[kbps]) to make the
                                          // above statement meet the spec.

inline constexpr size_t MAX_EVENT_FREQUENCY_HZ = 1000;

#define AUX_SYNC_UART (uart0)
inline constexpr size_t AUX_SYNC_DEFAULT_BAUDRATE  = 1000;

// Aux Baud rate should be faster than this minimum baud rate, or we will not
// have enough time to emit a full 4-byte (+1 start and 1 stop bit) message at 1Hz.
inline constexpr size_t MIN_AUX_SYNC_BAUDRATE = 40;
// Aux Baud rate should be slower than this value.
inline constexpr size_t MAX_AUX_SYNC_BAUDRATE = 1'000'000;

inline constexpr uint32_t AUX_PIN = 0;
inline constexpr uint32_t AUX_SYNC_START_OFFSET_US = 0;

#define LED0_PIN (24)
#define LED1_PIN (25)

#endif // CONFIG_H

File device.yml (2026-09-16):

%YAML 1.1
---
# yaml-language-server: $schema=https://harp-tech.org/draft-02/schema/device.json
device: WhiteRabbit
whoAmI: 1404
firmwareVersion: "0.1"
hardwareTargets: "1.0"
registers:
  ConnectedDevices:
    address: 32
    type: U16
    access: Event
    maskType: ClockOutChannels
    description: "The currently connected output channels. An event will be generated when any of the channels are connected or disconnected."
  Counter:
    address: 33
    type: U32
    access: [Write, Event]
    description: "The counter value. This value is incremented at the frequency specified by CounterFrequencyHz. Write to force a counter value."
  CounterFrequencyHz:
    address: 34
    type: U16
    access: Write
    maxValue: 500
    defaultValue: 0
    minValue: 0
    description: "The frequency at which the counter is incremented. A value of 0 disables the counter."
  AuxPortMode:
    address: 35
    type: U8
    access: Write
    description: "The function of the auxiliary port."
    maskType: AuxPortModeConfig
  AuxPortBaudRate:
    address: 36
    type: U32
    access: Write
    defaultValue: 1000
    minValue: 40
    maxValue: 1000000
    description: "The baud rate, in bps, of the auxiliary port when in HarpClock mode."

bitMasks:
  ClockOutChannels:
    description: "Clock output channels"
    bits:
      None: 0x00
      Channel0: 0x01
      Channel1: 0x02
      Channel2: 0x04
      Channel3: 0x08
      Channel4: 0x10
      Channel5: 0x20
      Channel6: 0x40
      Channel7: 0x80
      Channel8: 0x100
      Channel9: 0x200
      Channel10: 0x400
      Channel11: 0x800
      Channel12: 0x1000
      Channel13: 0x2000
      Channel14: 0x4000
      Channel15: 0x8000
groupMasks:
  AuxPortModeConfig:
    description: "Auxiliary port available configuration"
    values:
      Disabled: 0x0
      HarpClock: 0x1
      PPS: 0x2

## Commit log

2024-05-20 draft schematic
    [clk_outputs_0_thru_7.kicad_sch, clk_outputs_8_thru_16.kicad_sch, clock_sync_16.kicad_pcb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]
2024-05-30 route pcb v0.1
    [clk_outputs_0_thru_7.kicad_sch, clk_outputs_8_thru_16.kicad_sch, clock_sync_16.kicad_pcb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]
2024-05-31 draft v0.1 pcb
    [clock_sync_16.kicad_pcb, clock_sync_16.kicad_sch, rp2040_with_usb.kicad_sch]
2024-06-21 draft firmware
    [clk_outputs_0_thru_7.kicad_sch, clk_outputs_8_thru_16.kicad_sch, clock_sync_16.kicad_pcb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]
2024-07-16 dispatch works
    [clk_outputs_0_thru_7.kicad_sch]
2024-07-18 add timer msg example
2024-07-18 add read-connected-devices demo
2024-07-23 add short git hash to CMakeLists.txt
    [main.cpp, white_rabbit_app.cpp]
2024-07-23 add enclosure
    [bottom_lid.DXF, case_walls.STL, enclosure_walls.STL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]
2024-07-25 Add draft of device.yml
2024-07-30 Normalize directory to other aind harp device packages
2024-08-23 update case
    [case_walls.STL, enclosure_walls.STL]
2024-08-23 update enclosure
    [bottom_lid.DXF, bottom_lid_offset.DXF, top_lid.DXF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]
2024-09-04 add pps/slow_uart output options
    [board_power.kicad_sch, clk_outputs_0_thru_7.kicad_sch, clk_outputs_8_thru_16.kicad_sch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]
2024-09-09 add aux uart baud rate
2024-09-09 fix aux baud rate off-by-1
    [white_rabbit_app.cpp]
2024-09-09 add enable aux uart example
2024-09-12 Hint baud rate limits in device schema
2024-09-12 clamp max baud rate
2024-09-12 Bump firmware device in schema
2024-09-12 Update hardware targets in device schema
2024-09-18 implement software-based aux uart
2025-01-24 update harp core & uart lib
2025-02-21 update harp core; update led resistors and deprecated parts; bump versions
    [clk_outputs_0_thru_7.kicad_sch, clk_outputs_8_thru_16.kicad_sch, clock_sync_16.kicad_pcb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]
2025-02-21 update missing BOM field
    [clk_outputs_0_thru_7.kicad_sch, clk_outputs_8_thru_16.kicad_sch, clock_sync_16.kicad_pcb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]
2026-09-14 update pico core
2026-09-14 sync pico core lib with main branch
